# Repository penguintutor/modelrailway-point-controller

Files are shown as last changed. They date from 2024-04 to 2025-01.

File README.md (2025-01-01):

# Model railway point controller

The model railway point controller provides a way to control up to 4 points using a Raspberry Pi Pico W. It includes a MOSFET based capacitor discharge unit on the PCB and MOSFET controllers for each of the point motors.

It includes a second control board connected by I2C which can be connected to physical LEDs and switches to provide a way to control the points. The points can also be controlled using a web interface which can also be used in conjunction with GUI software to provide a touch screen interface.

# Installation

This version needs to be installed on a Raspberry Pi Pico W with the appropriate network enabled MicroPython. MicroPython can be installed through the Thonny editor.

To install the program, copy all the files in the pico-src directory to the top-level of the Raspberry Pi Pico. For the network connection you also need to create a file called secrets.py with details of your SSID and PASSWORD. The example below shows the formatting for the secrets.py file.

    SSID="NetworkSSID"
    PASSWORD="WiFiPassword"
    
## Configuration

The program can be run in two modes. 

* Access Point Mode (AP mode) - In this mode the Pico will act as a Wireless Access Point which you can connect to using another WiFi enabled device.
* Client Mode - In this mode you can connect to an existing wireless network

Note that in client mode it is currently blocking and will not operate until it has successfully connected to the network.

The mode is set by editing the entry "mode" in the pico-lights.py file. 

mode="ap"       # Use as an access point
mode="client"   # Use as a Wi-Fi client

## Running on startup

For the code to run automatically on start-up save the pico-point-controller.py file on your Pico as main.py.

## Using without the I2C control board

The board can be used in WiFi only mode, which does not use the I2C based switch and LED board. For that use the file pico-point-controller.wifionly.py instead of pico-point-controller.py (or save as main.py for auto-run) 

# More Information

For more details see [www.penguintutor.com/points](https://www.penguintutor.com/points)

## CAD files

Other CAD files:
enclosure/interface-only/point-controller-box-interface-v0.6.0.FCStd
enclosure/self-enclosed/point-controller-box-v0.5.5.FCStd

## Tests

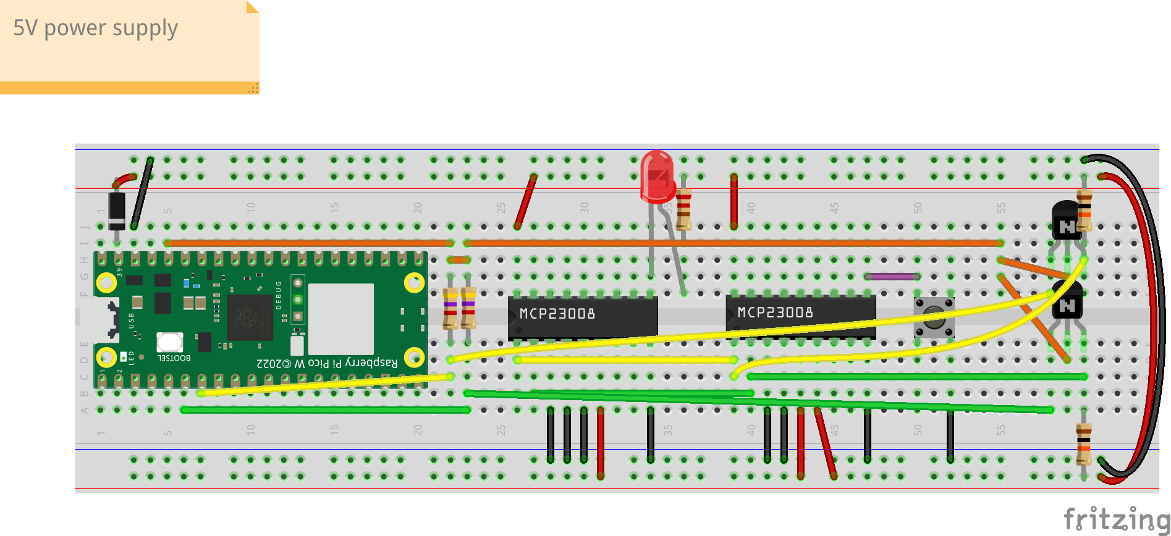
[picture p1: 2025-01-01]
electronics/breadboard-testing/switch-interfacev2_bb.png

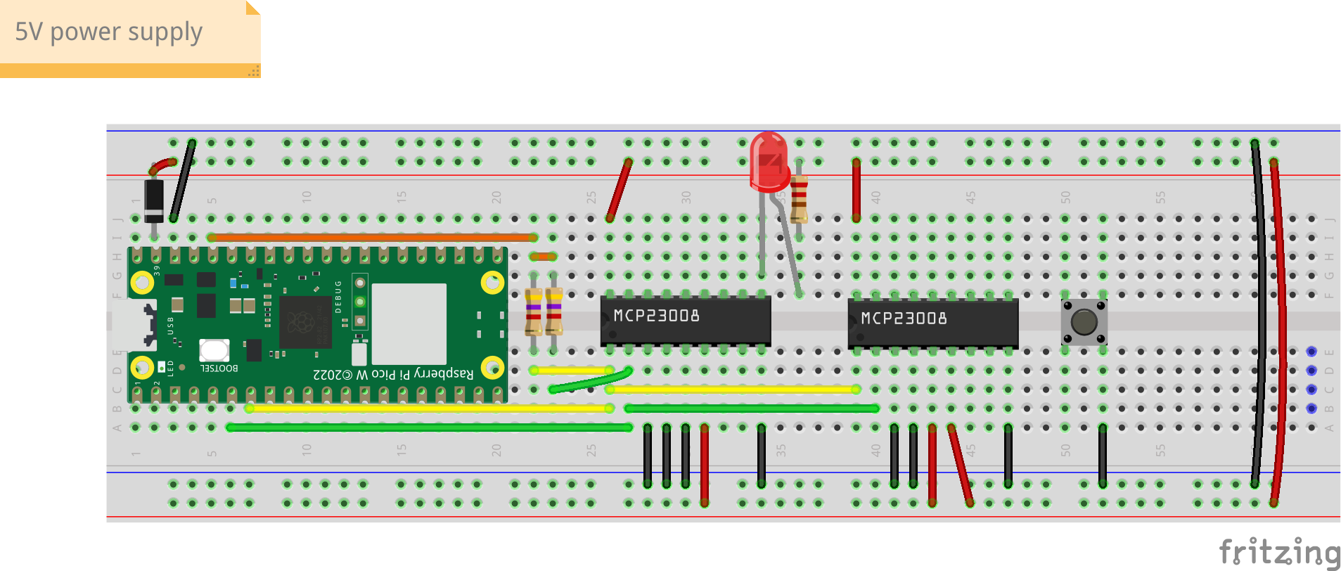
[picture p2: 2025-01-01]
electronics/breadboard-testing/switch-interface_bb.png

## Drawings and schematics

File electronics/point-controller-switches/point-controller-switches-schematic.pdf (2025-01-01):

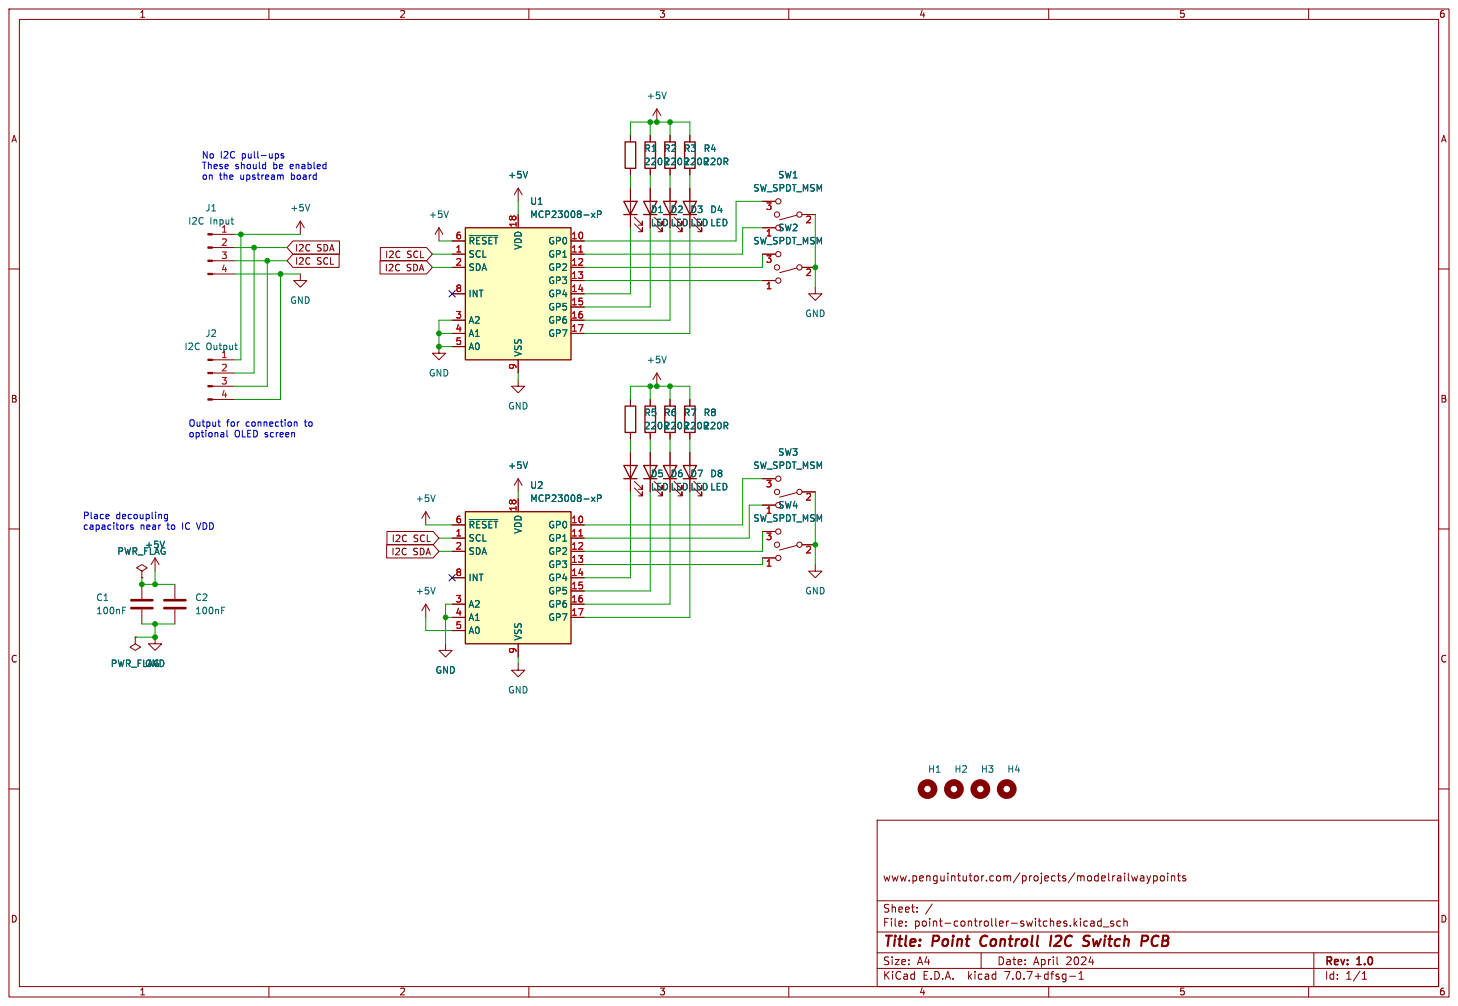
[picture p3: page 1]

I2C SDA I2C SCL No I2C pull-ups These should be enabled
I2C Output 1

File: point-controller-switches.kicad_sch Sheet: / www.penguintutor.com/projects/modelrailwaypoints GND

Id: 1/1 Title: Point Controll I2C Switch PCB

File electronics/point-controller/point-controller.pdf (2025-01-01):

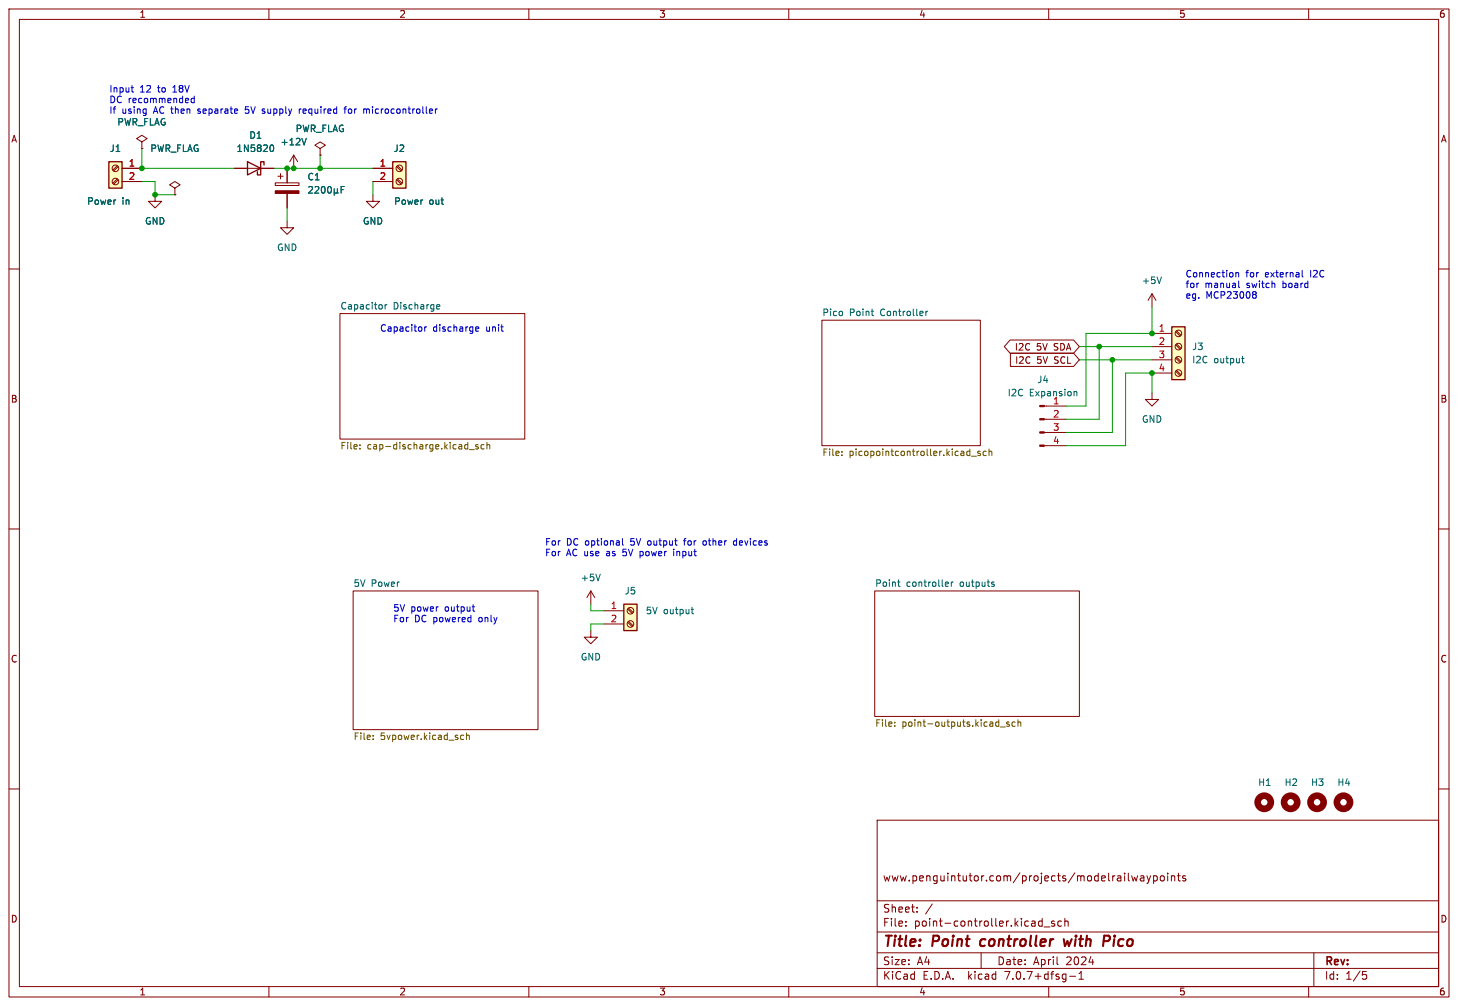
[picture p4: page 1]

Input 12 to 18V DC recommended

for manual switch board

File: point-controller.kicad_sch Sheet: / www.penguintutor.com/projects/modelrailwaypoints

Id: 1/5 Title: Point controller with Pico

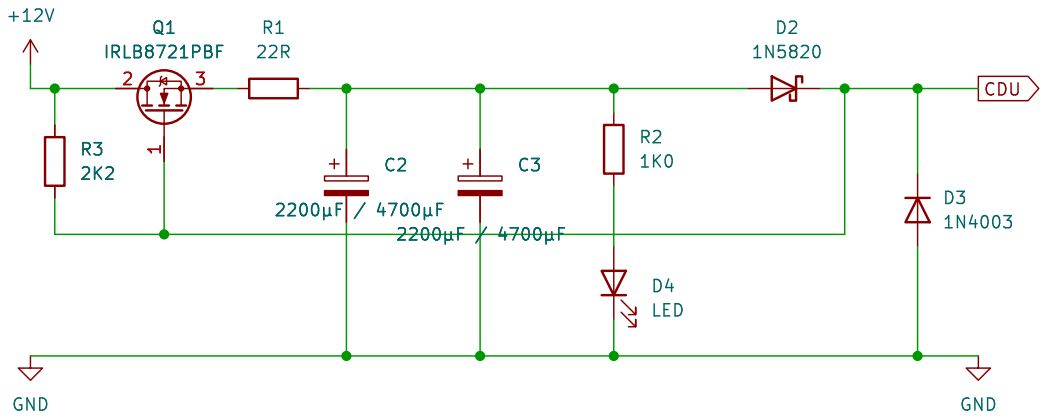
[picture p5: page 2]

www.penguintutor.com/projects/modelrailwaypoints

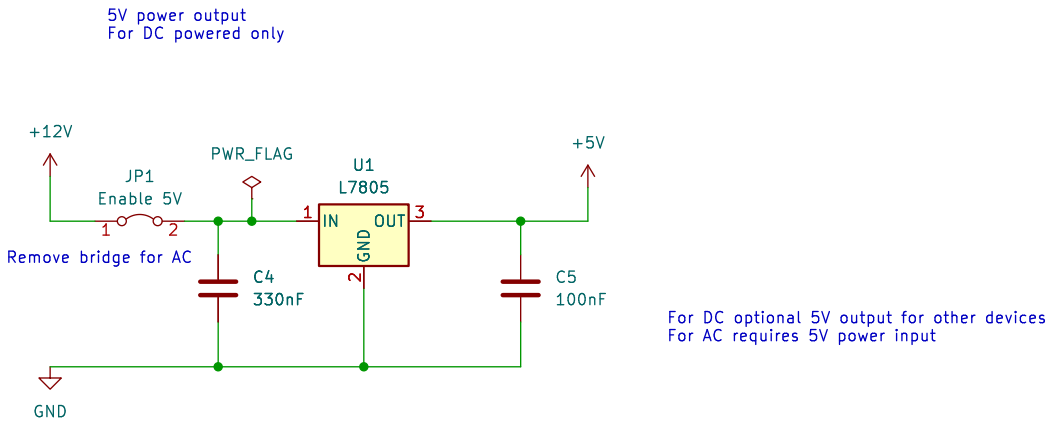
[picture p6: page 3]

330nF Remove bridge for AC

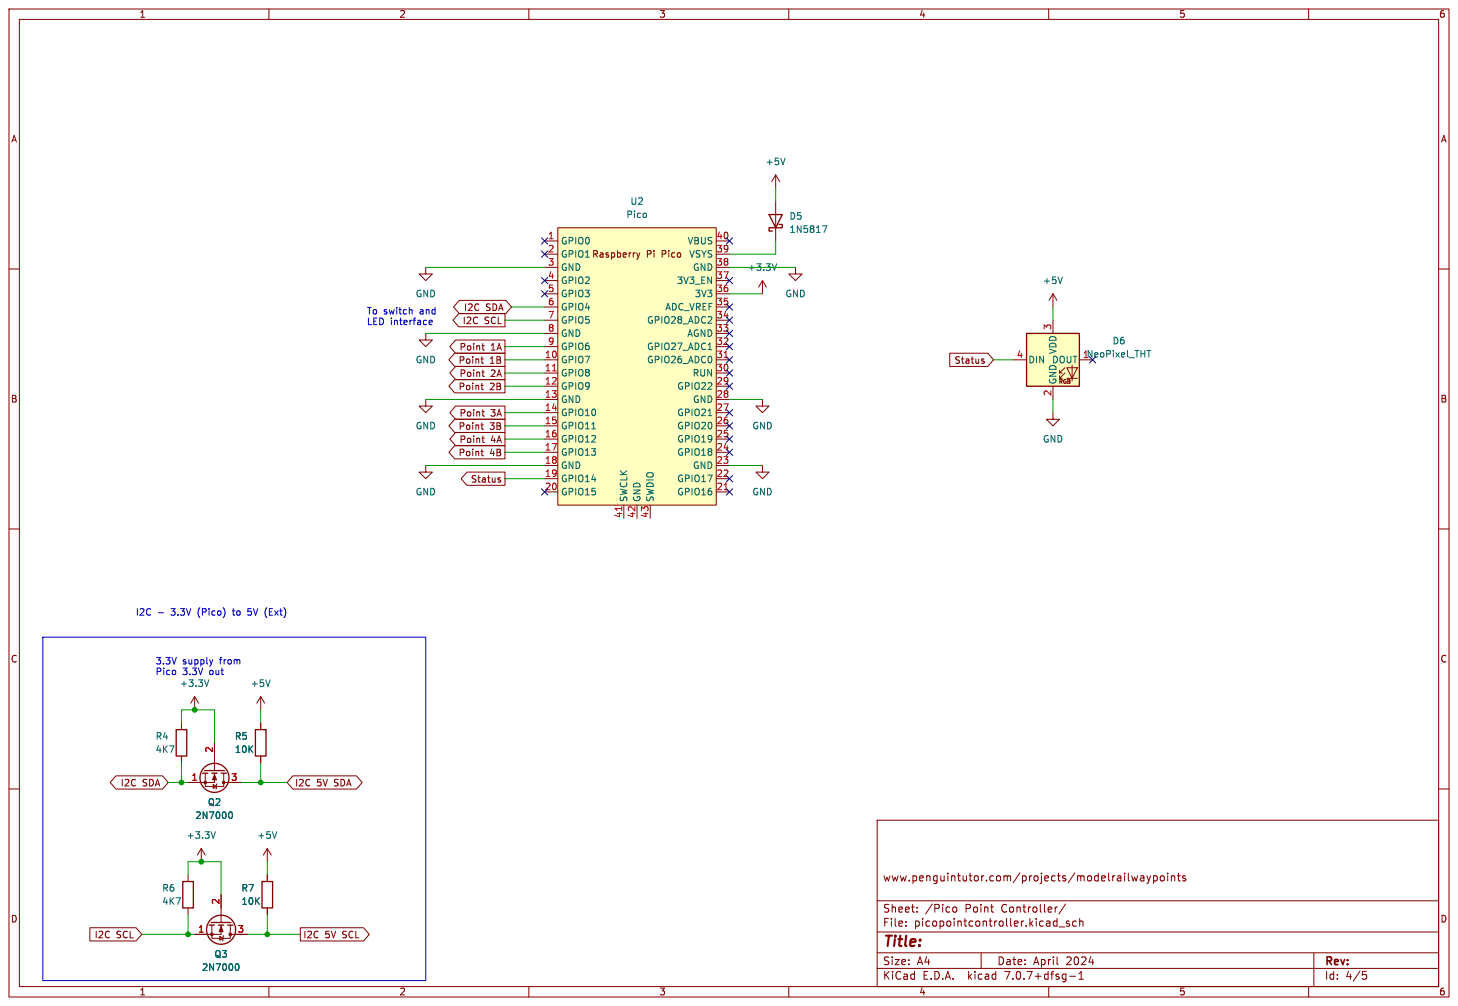
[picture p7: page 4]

I2C - 3.3V (Pico) to 5V (Ext) 3.3V supply from

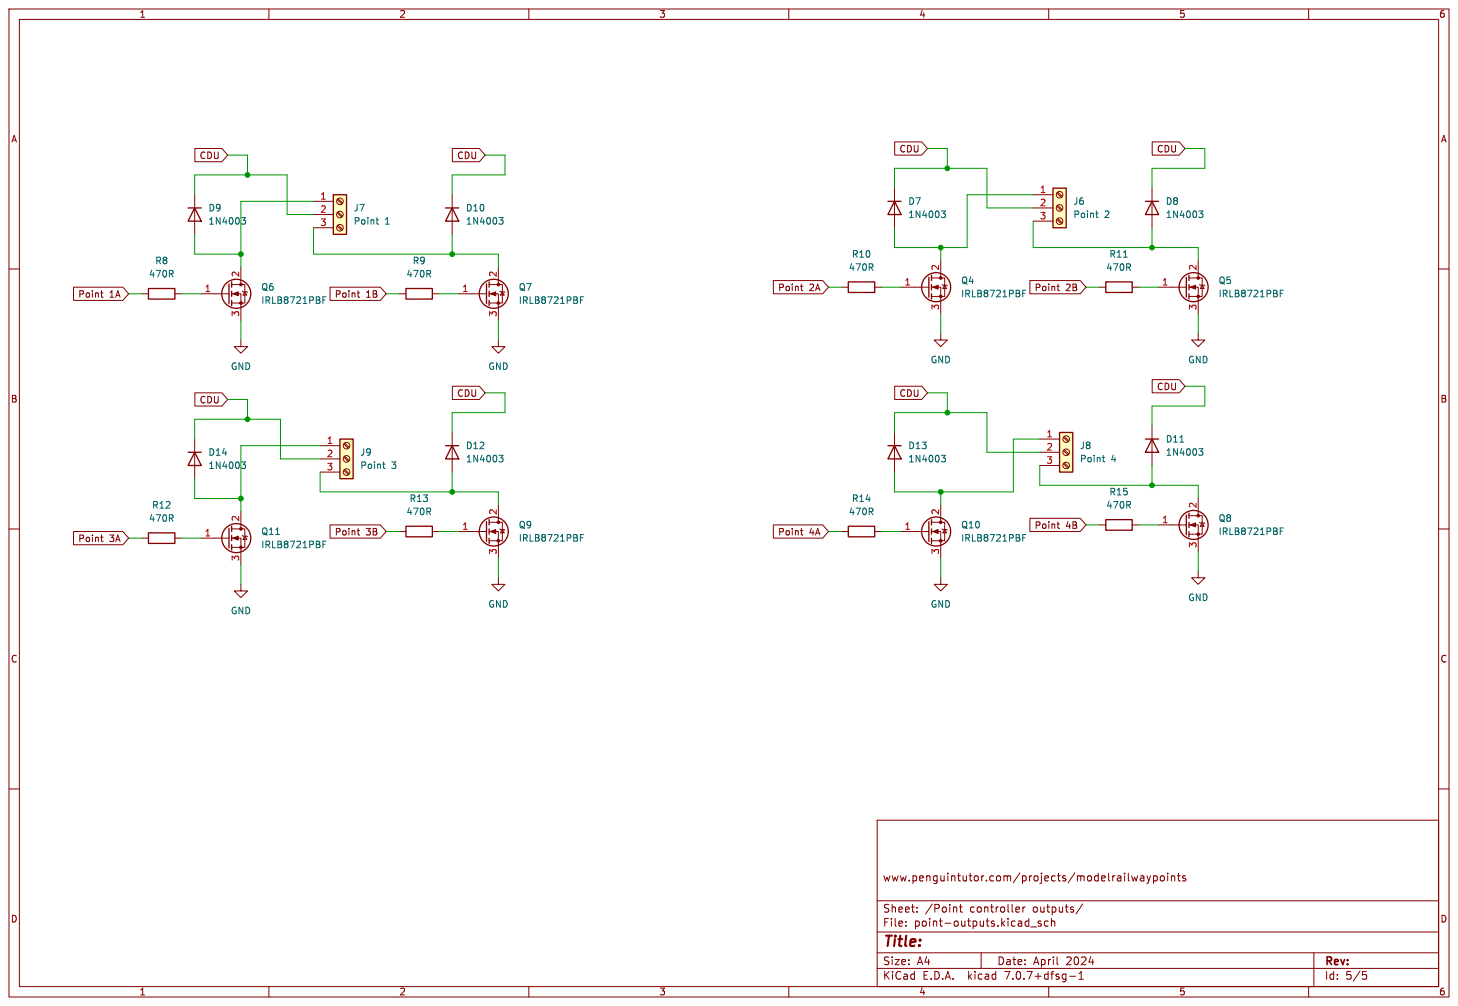
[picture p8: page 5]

www.penguintutor.com/projects/modelrailwaypoints

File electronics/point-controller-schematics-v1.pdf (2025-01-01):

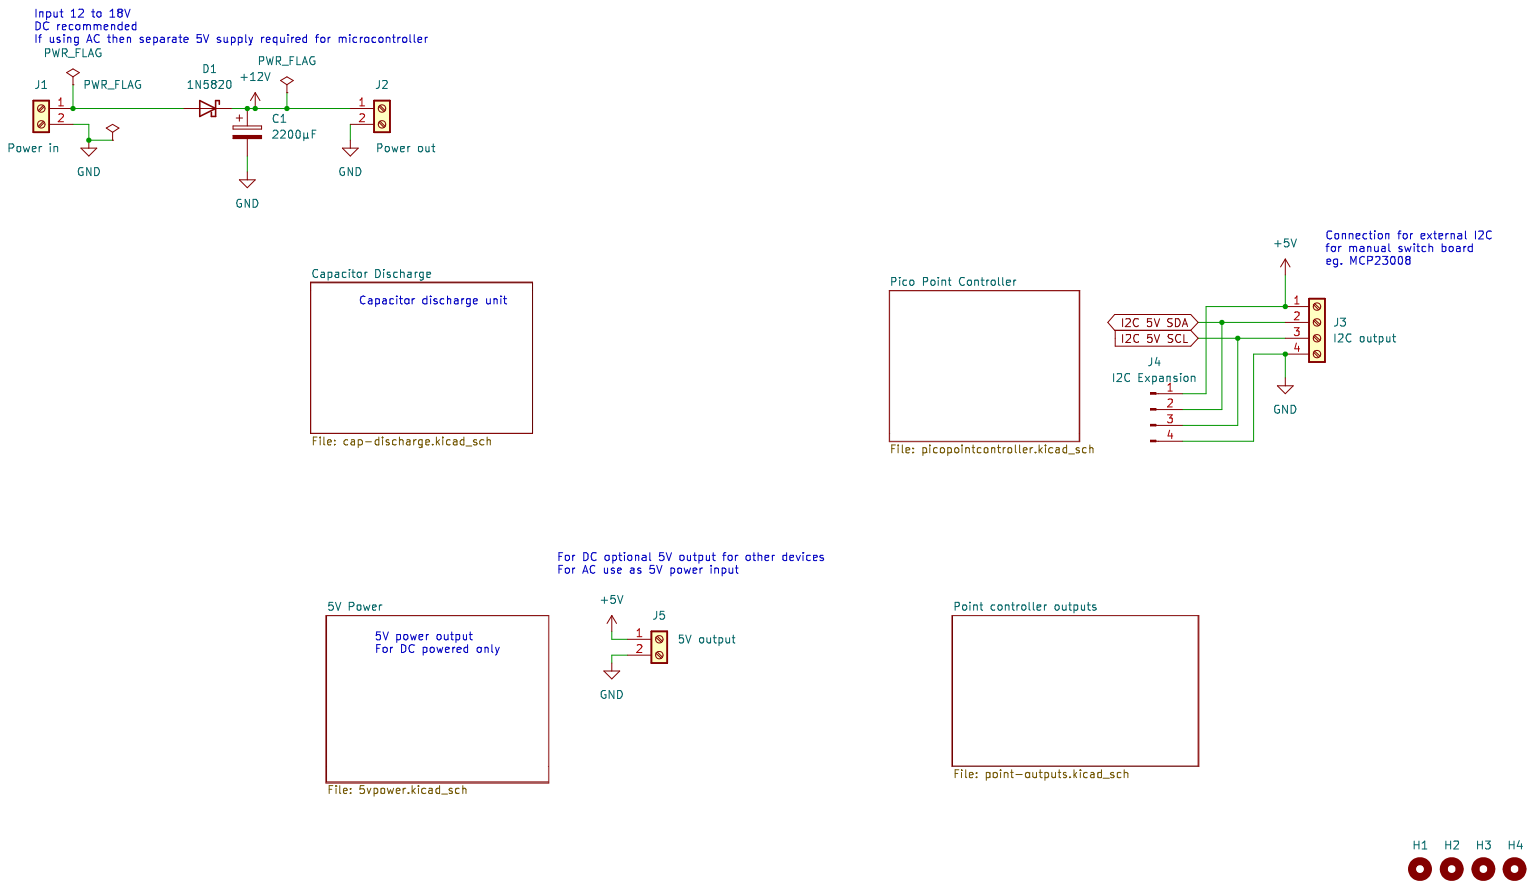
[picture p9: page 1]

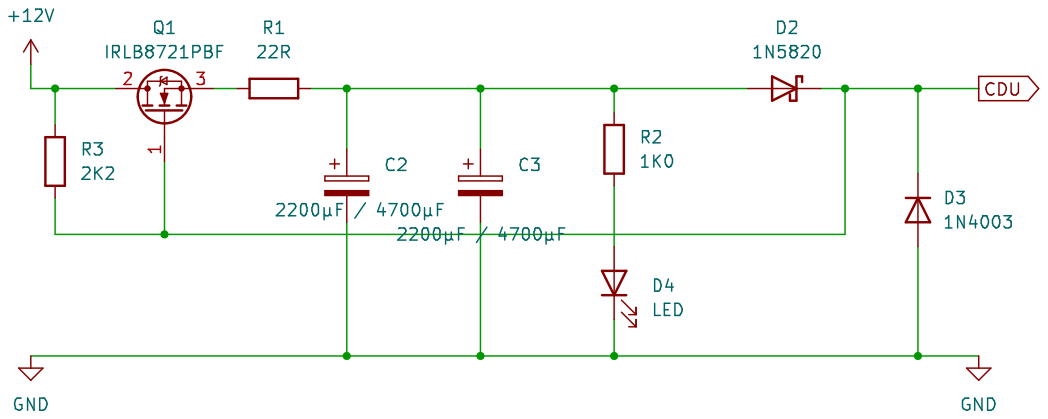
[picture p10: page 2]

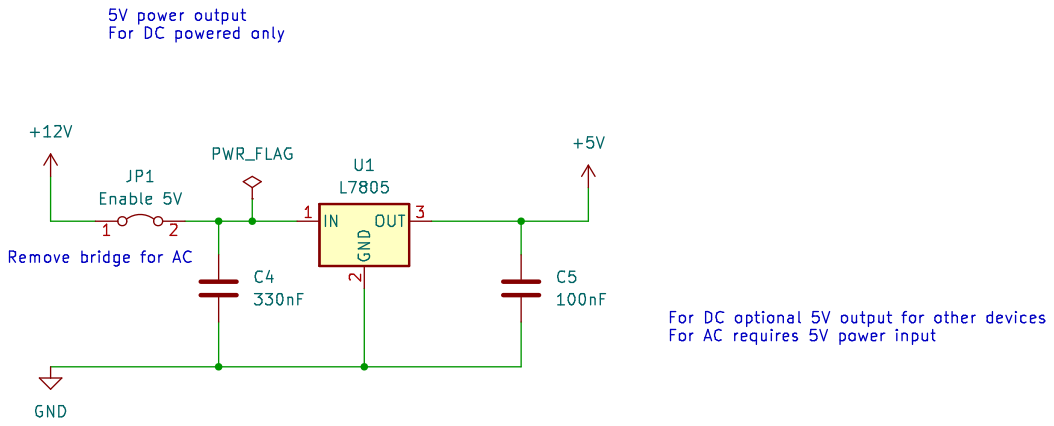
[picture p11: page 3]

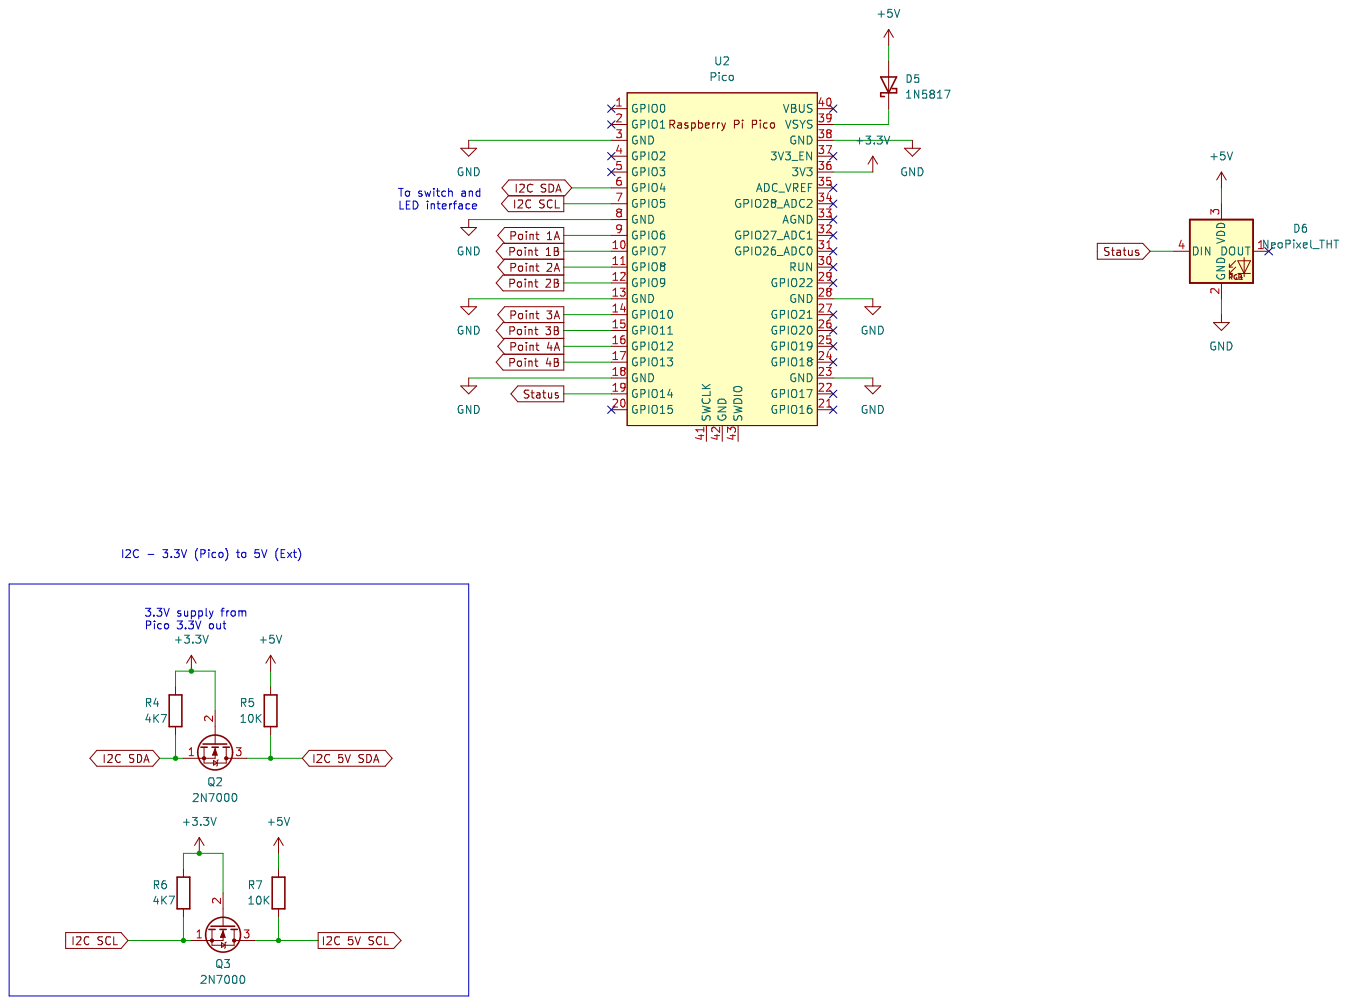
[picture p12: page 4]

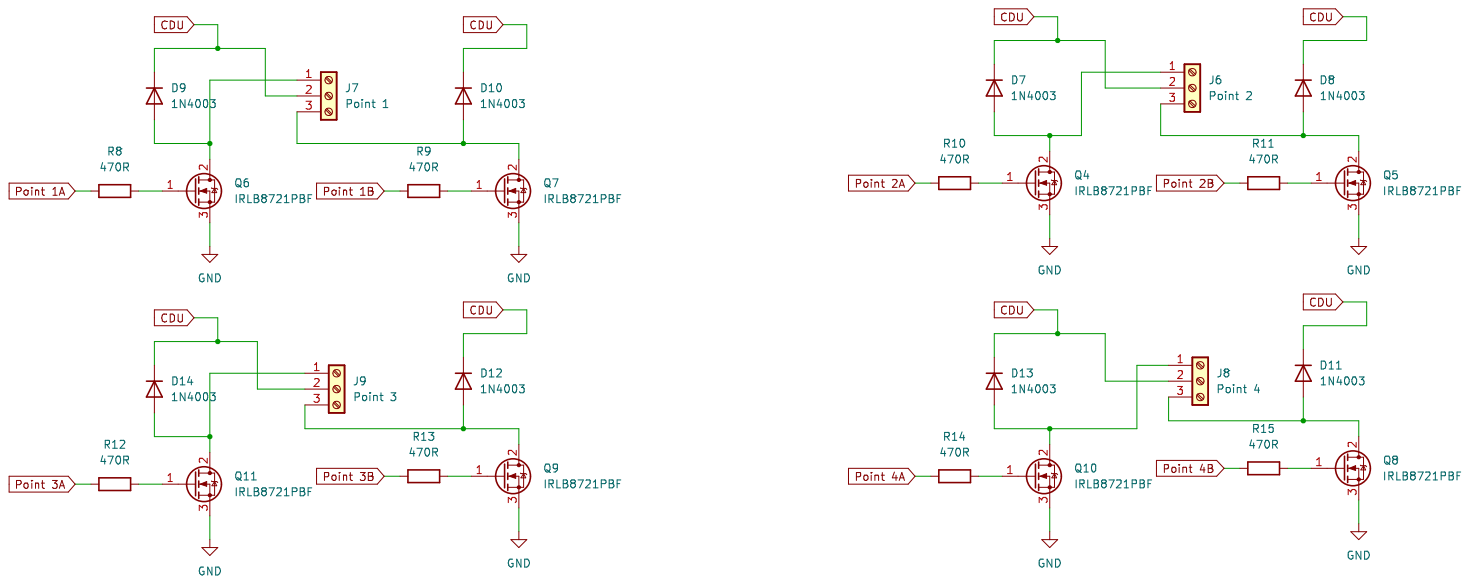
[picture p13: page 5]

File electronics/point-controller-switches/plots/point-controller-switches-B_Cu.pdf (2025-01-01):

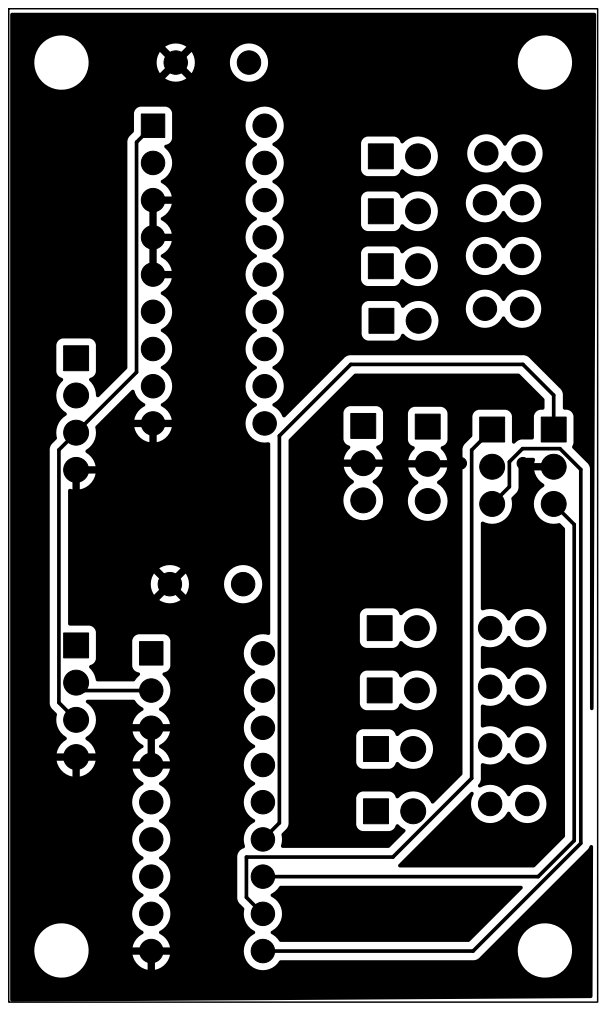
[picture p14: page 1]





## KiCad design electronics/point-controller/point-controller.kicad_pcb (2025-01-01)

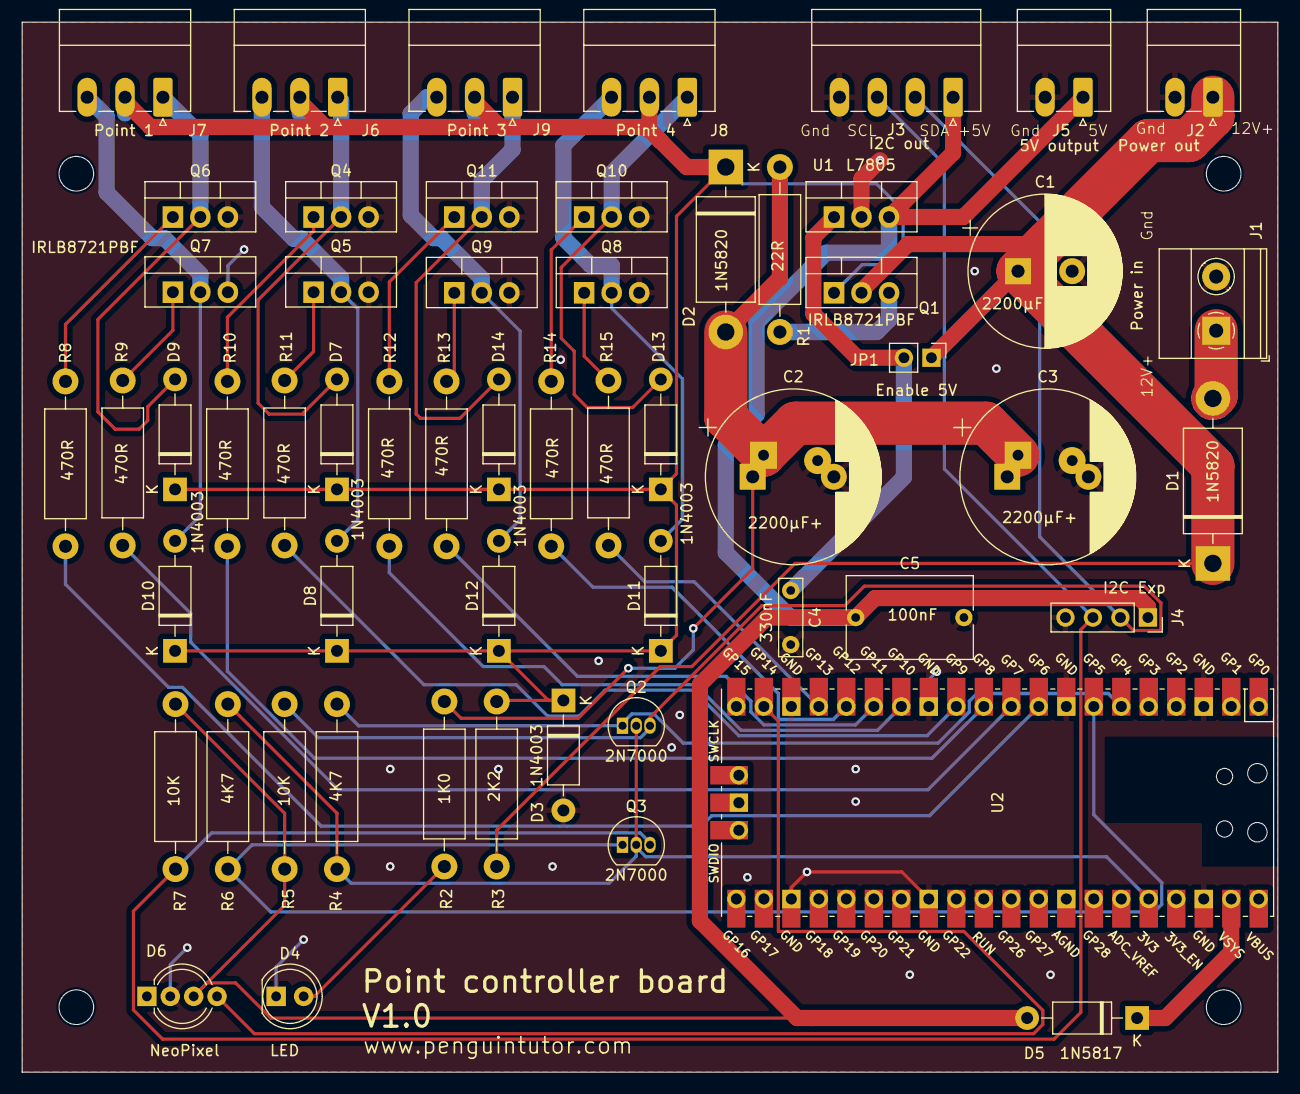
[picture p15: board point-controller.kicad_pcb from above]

Board: 2 copper layers, 116.0 x 97.0 mm, 61 parts (0 on the bottom side), 40 nets.

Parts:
C1: 2200μF; CP_Radial_D14.0mm_P5.00mm
C2, C3: 2200μF+; CP_Radial_D16.0mm_P7.50mm_P5.00mm
C4: 330nF; C_Rect_L7.0mm_W2.0mm_P5.00mm
C5: 100nF; C_Rect_L11.5mm_W7.5mm_P10.00mm_MKT
D1, D2: 1N5820; D_DO-201AD_P15.24mm_Horizontal
D3, D7, D8, D9, D10, D11, D12, D13, D14: 1N4003; D_DO-41_SOD81_P10.16mm_Horizontal
D4: LED; LED_D5.0mm
D5: 1N5817; D_DO-41_SOD81_P10.16mm_Horizontal
D6: NeoPixel; LED_D5.0mm-4_RGB_Wide_Pins
H1, H2, H3, H4: MountingHole; MountingHole_3.2mm_M3
J1: Power in; TerminalBlock_Phoenix_MKDS-1,5-2_1x02_P5.00mm_Horizontal
J2: Power out; PhoenixContact_MC_1,5_2-G-3.5_1x02_P3.50mm_Horizontal
J3: I2C out; PhoenixContact_MC_1,5_4-G-3.5_1x04_P3.50mm_Horizontal
J4: I2C Exp; PinSocket_1x04_P2.54mm_Vertical
J5: 5V output; PhoenixContact_MC_1,5_2-G-3.5_1x02_P3.50mm_Horizontal
J6: Point 2; PhoenixContact_MC_1,5_3-G-3.5_1x03_P3.50mm_Horizontal
J7: Point 1; PhoenixContact_MC_1,5_3-G-3.5_1x03_P3.50mm_Horizontal
J8: Point 4; PhoenixContact_MC_1,5_3-G-3.5_1x03_P3.50mm_Horizontal
J9: Point 3; PhoenixContact_MC_1,5_3-G-3.5_1x03_P3.50mm_Horizontal
JP1: Enable 5V; PinHeader_1x02_P2.54mm_Vertical
Q1, Q4, Q5, Q6, Q7, Q8, Q9, Q10, Q11: IRLB8721PBF; TO-220-3_Vertical
Q2, Q3: 2N7000; TO-92_Inline
R1: 22R; R_Axial_DIN0411_L9.9mm_D3.6mm_P15.24mm_Horizontal
R2: 1K0; R_Axial_DIN0411_L9.9mm_D3.6mm_P15.24mm_Horizontal
R3: 2K2; R_Axial_DIN0411_L9.9mm_D3.6mm_P15.24mm_Horizontal
R4, R6: 4K7; R_Axial_DIN0411_L9.9mm_D3.6mm_P15.24mm_Horizontal
R5, R7: 10K; R_Axial_DIN0411_L9.9mm_D3.6mm_P15.24mm_Horizontal
R8, R9, R10, R11, R12, R13, R14, R15: 470R; R_Axial_DIN0411_L9.9mm_D3.6mm_P15.24mm_Horizontal
U1: L7805; TO-220-3_Vertical
U2: Pico; RPi_Pico_SMD_TH

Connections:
+3.3V: Q2.2 (G), Q3.2 (G), R4.1, R6.1, U2.36 (3V3)
+5V: C5.1, D5.2 (A), D6.3 (VDD), J3.1, J4.1, J5.1, R5.1, R7.1, U1.3 (OUT)
+12V: C1.1, D1.1 (K), J2.1, JP1.1 (A), Q1.2 (D), R3.1
CDU: D2.1 (K), D3.1 (K), D7.1 (K), D8.1 (K), D9.1 (K), D10.1 (K), D11.1 (K), D12.1 (K), D13.1 (K), D14.1 (K), J6.2, J7.2, J8.2, J9.2, Q1.1 (G), R3.2
GND: C1.2, C2.2, C3.2, C4.2, C5.2, D3.2 (A), D4.1 (K), D6.2 (GND), J1.2, J2.2, J3.4, J4.4, J5.2, Q4.3 (S), Q5.3 (S), Q6.3 (S), Q7.3 (S), Q8.3 (S), Q9.3 (S), Q10.3 (S), Q11.3 (S), U1.2 (GND), U2.3 (GND), U2.8 (GND), U2.13 (GND), U2.18 (GND), U2.23 (GND), U2.28 (GND), U2.38 (GND)
I2C 5V SCL: J3.3, J4.3, Q3.3 (D), R7.2
I2C 5V SDA: J3.2, J4.2, Q2.3 (D), R5.2
I2C SCL: Q3.1 (S), R6.2, U2.7 (GPIO5)
I2C SDA: Q2.1 (S), R4.2, U2.6 (GPIO4)
unnamed: D1.2 (A), J1.1
unnamed: C2.1, C3.1, D2.2 (A), R1.2, R2.1
unnamed: D4.2 (A), R2.2
unnamed: D5.1 (K), U2.39 (VSYS)
unnamed: D7.2 (A), J6.1, Q4.2 (D)
unnamed: D8.2 (A), J6.3, Q5.2 (D)
unnamed: D9.2 (A), J7.1, Q6.2 (D)
unnamed: D10.2 (A), J7.3, Q7.2 (D)
unnamed: D11.2 (A), J8.3, Q8.2 (D)
unnamed: D12.2 (A), J9.3, Q9.2 (D)
unnamed: D13.2 (A), J8.1, Q10.2 (D)
unnamed: D14.2 (A), J9.1, Q11.2 (D)
unnamed: C4.1, JP1.2 (B), U1.1 (IN)
unnamed: Q1.3 (S), R1.1
unnamed: Q4.1 (G), R10.2
unnamed: Q5.1 (G), R11.2
unnamed: Q6.1 (G), R8.2
unnamed: Q7.1 (G), R9.2
unnamed: Q8.1 (G), R15.2
unnamed: Q9.1 (G), R13.2
unnamed: Q10.1 (G), R14.2
unnamed: Q11.1 (G), R12.2
Point 1A: R8.1, U2.9 (GPIO6)
Point 1B: R9.1, U2.10 (GPIO7)
Point 2A: R10.1, U2.11 (GPIO8)
Point 2B: R11.1, U2.12 (GPIO9)
Point 3A: R12.1, U2.14 (GPIO10)
Point 3B: R13.1, U2.15 (GPIO11)
Point 4A: R14.1, U2.16 (GPIO12)
Point 4B: R15.1, U2.17 (GPIO13)
Status: D6.4 (DIN), U2.19 (GPIO14)

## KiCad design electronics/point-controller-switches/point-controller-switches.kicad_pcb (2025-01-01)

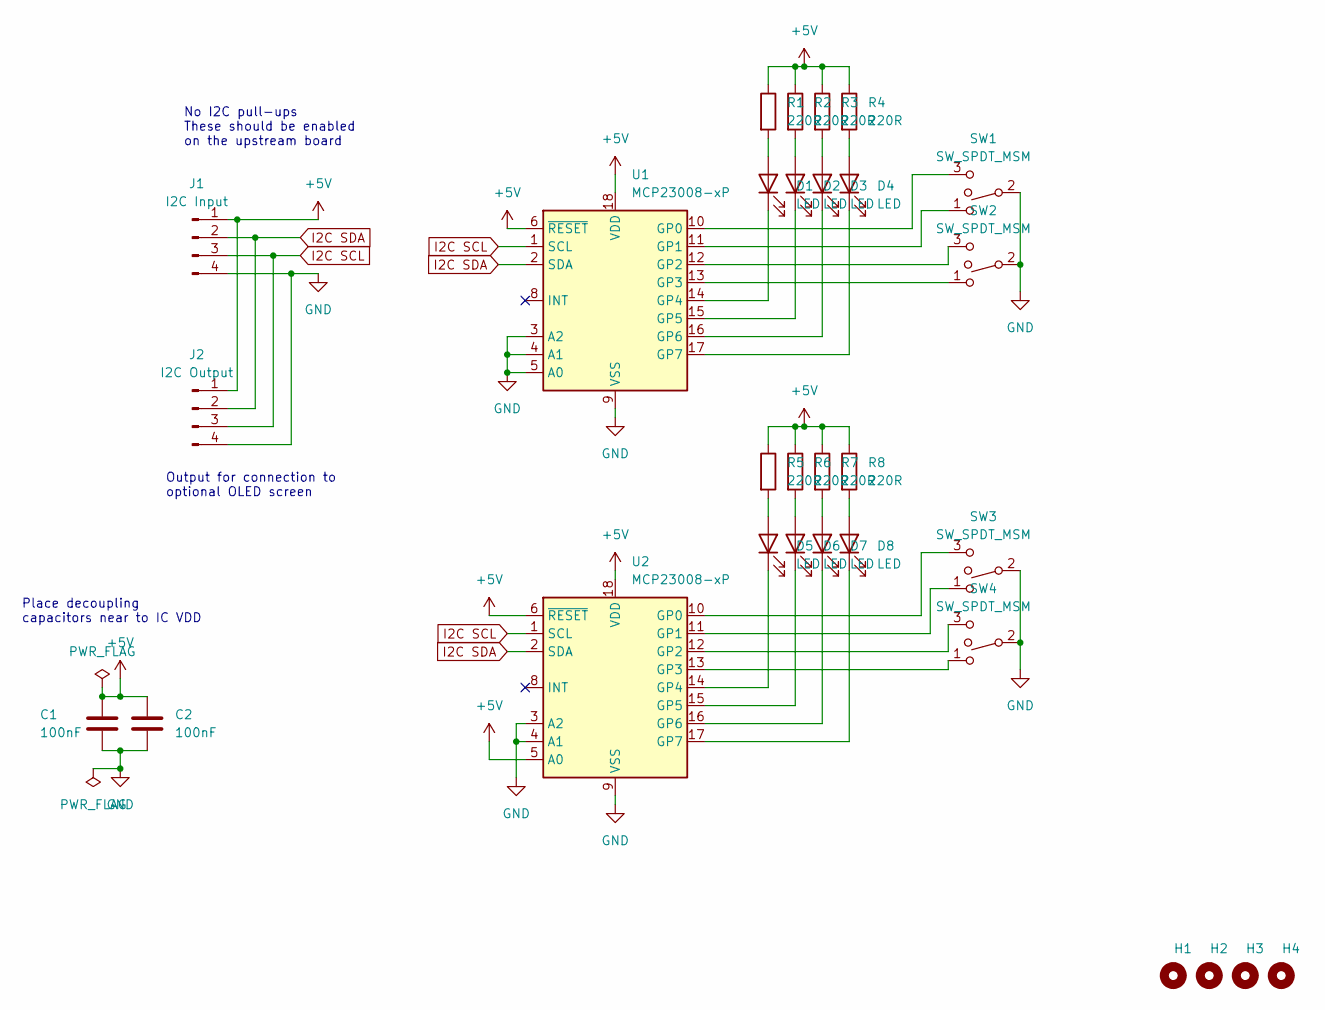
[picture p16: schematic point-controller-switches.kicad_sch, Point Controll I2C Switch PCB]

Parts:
C1, C2: 100nF; C_Disc_D4.3mm_W1.9mm_P5.00mm
D1, D2, D3, D4, D5, D6, D7, D8: LED; PinHeader_1x02_P2.54mm_Vertical
H1, H2, H3, H4: MountingHole; MountingHole_3.2mm_M3
J1: I2C Input; PinHeader_1x04_P2.54mm_Vertical
J2: I2C Output; PinHeader_1x04_P2.54mm_Vertical
R1, R2, R3, R4, R5, R6, R7, R8: 220R; R_Axial_DIN0207_L6.3mm_D2.5mm_P2.54mm_Vertical
SW1, SW2, SW3, SW4: SW_SPDT_MSM; PinHeader_1x03_P2.54mm_Vertical
U1, U2: MCP23008-xP; DIP-18_W7.62mm

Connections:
+5V: C1.1, C2.1, J1.1, J2.1, R1.1, R2.1, R3.1, R4.1, R5.1, R6.1, R7.1, R8.1, U1.6 (~RESET), U1.18 (VDD), U2.5 (A0), U2.6 (~RESET), U2.18 (VDD)
GND: C1.2, C2.2, J1.4, J2.4, SW1.2, SW2.2, SW3.2, SW4.2, U1.3 (A2), U1.4 (A1), U1.5 (A0), U1.9 (VSS), U2.3 (A2), U2.4 (A1), U2.9 (VSS)
I2C SCL: J1.3, J2.3, U1.1 (SCL), U2.1 (SCL)
I2C SDA: J1.2, J2.2, U1.2 (SDA), U2.2 (SDA)
unnamed: D1.2 (A), R1.2
unnamed: D1.1 (K), U1.14 (GP4)
unnamed: D2.2 (A), R2.2
unnamed: D2.1 (K), U1.15 (GP5)
unnamed: D3.2 (A), R3.2
unnamed: D3.1 (K), U1.16 (GP6)
unnamed: D4.2 (A), R4.2
unnamed: D4.1 (K), U1.17 (GP7)
unnamed: D5.2 (A), R5.2
unnamed: D5.1 (K), U2.14 (GP4)
unnamed: D6.2 (A), R6.2
unnamed: D6.1 (K), U2.15 (GP5)
unnamed: D7.2 (A), R7.2
unnamed: D7.1 (K), U2.16 (GP6)
unnamed: D8.2 (A), R8.2
unnamed: D8.1 (K), U2.17 (GP7)
unnamed: SW1.3, U1.10 (GP0)
unnamed: SW1.1, U1.11 (GP1)
unnamed: SW2.3, U1.12 (GP2)
unnamed: SW2.1, U1.13 (GP3)
unnamed: SW3.3, U2.10 (GP0)
unnamed: SW3.1, U2.11 (GP1)
unnamed: SW4.3, U2.12 (GP2)
unnamed: SW4.1, U2.13 (GP3)

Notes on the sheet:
Place decoupling capacitors near to IC VDD
Output for connection to optional OLED screen
No I2C pull-ups These should be enabled on the upstream board

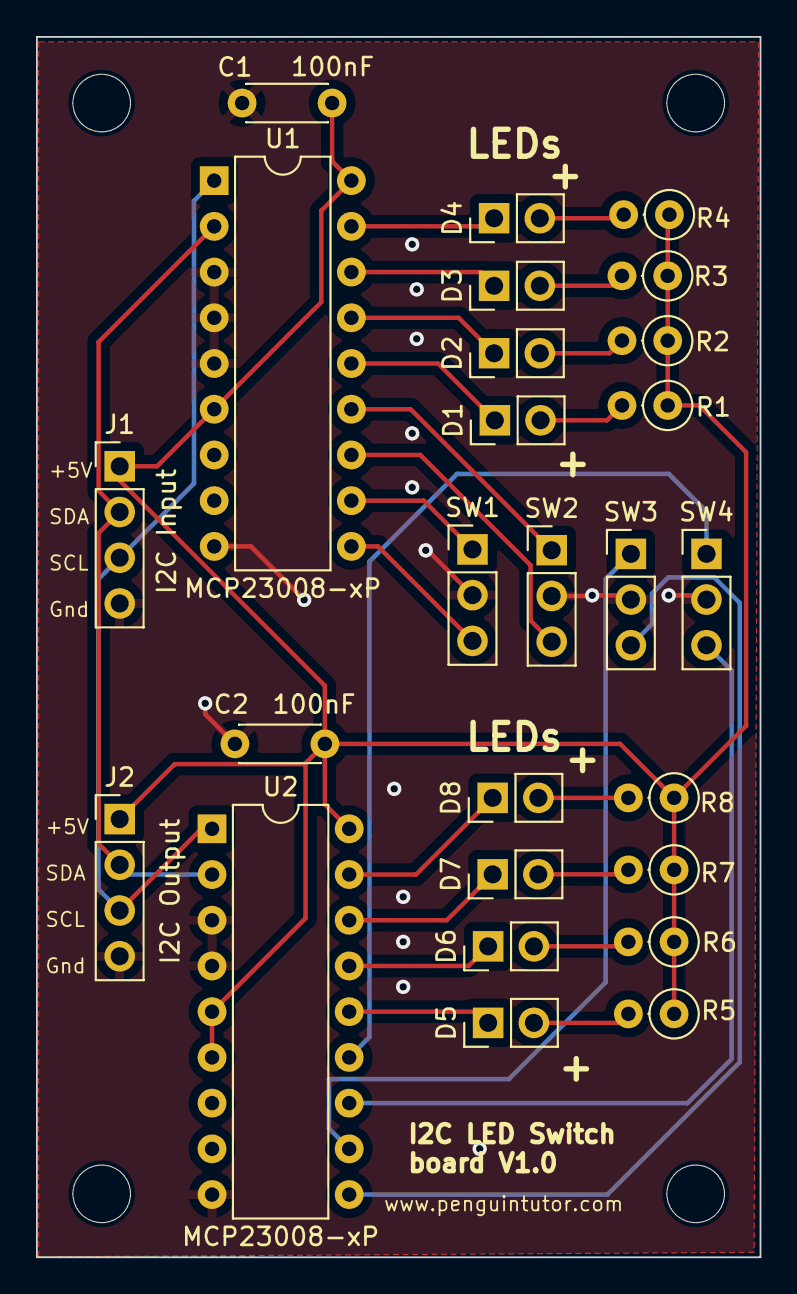
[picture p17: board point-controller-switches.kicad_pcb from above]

Board: 2 copper layers, 40.2 x 67.8 mm, 30 parts (0 on the bottom side), 28 nets.

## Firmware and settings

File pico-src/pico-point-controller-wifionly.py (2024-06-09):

# Code for controlling Model Railway points
# Point controller board
# Also needs secrets.py with WiFi login details
# For more details see: https://www.penguintutor.com/points

# Alternative to pico-point-controller.py to allow testing of
# main board without being connected to add-on switch board

from machine import Pin
from utime import sleep
import network
import socket
import uasyncio as asyncio
import secrets
import re
from url_handler import URL_Handler
from pixelstatus import *
from point import Point
from controller import Controller

# Mode can be ap (access point where the Pico acts as a web server)
# or "client" [default] which connects to an existing network
# Note that client mode is blocking and will not run the rest of the code
# until a network connection is established
mode="client"

# Do we display light sequence on startup - helpful to test if working
intro = True

# All documents in DocumentRoot are publically accessible
DocumentRoot = "public/"

# If ip_config not blank then use for network config
# otherwise set to "" to use dhcp
ip_config = ("192.168.0.53", "255.255.255.0", "192.168.0.1", "8.8.8.8")

# Indexed at 0 (board labelling is 1)

controller = Controller((0,5,4), (0, 32, 33), i2c_control=False)

# Each of the points is created as an instance of point object
# Each of the pins is given a tuple representing controller number, followed by port number
# Pico is controller 0, MCP23008 are 1 and 2
# Point class uses controller, point0, point1, switch0, switch1, led0, led1
points = [
    Point(controller, (0,6), (0, 7), (1,0), (1,1), (1,4), (1,5)),
    Point(controller, (0,8), (0, 9), (1,2), (1,3), (1,6), (1,7)),
    Point(controller, (0,10), (0, 11), (2,0), (2,1), (2,4), (2,5)),
    Point(controller, (0,12), (0, 13), (2,2), (2,3), (2,6), (2,7))
]



url = URL_Handler(DocumentRoot)

      
def connect():
    #Connect to WLAN
    if mode== "ap":
        # Access Point mode
        ip = connect_ap_mode()
    else:
        ip = connect_client_mode()
    return ip
    


def connect_ap_mode ():
    wlan = network.WLAN(network.AP_IF)
    wlan.config(essid=secrets.SSID, password=secrets.PASSWORD)
    wlan.active(True)
    while wlan.active() == False:
        print ('Trying to setup AP mode')
    ip = wlan.ifconfig()[0]
    print('AP Mode is active')
    print('Connect to Wireless Network '+secrets.SSID)
    print('Connect to IP address '+ip)
    return ip

def connect_client_mode ():
    wlan = network.WLAN(network.STA_IF)
    wlan.active(True)
    wlan.config(pm = 0xa11140) # Disable power saving mode
    if ip_config != "":
        wlan.ifconfig(ip_config)
    wlan.connect(secrets.SSID, secrets.PASSWORD)
    while wlan.isconnected() == False:
        print('Waiting for connection...')
        sleep(1)
    ip = wlan.ifconfig()[0]
    print('Connect to IP address '+ip)    
    return ip



def setup_pins ():
    # List of inputs and outputs used in setup
    inputs = []
    outputs = []

    # Setup inputs and outputs
    for this_point in points:
        inputs.extend(this_point.get_inputs())
        outputs.extend(this_point.get_outputs())
    # Wifi only no inputs - next line commented out
    controller.set_inputs(inputs)
    controller.set_outputs(outputs)
    
    # Set all points to unknown state (both LEDs off)
    for this_point in points:
        this_point.unknown()
        
    if intro == True:
        # Quick flash intro
        for this_point in points:
            this_point.set_led(0, 1)
            sleep(0.5)
            this_point.set_led(0, 0)
            this_point.set_led(1, 1)
            sleep(0.5)
            this_point.set_led(1, 0)
            

async def serve_client(reader, writer):
    status_active()
    print("Client connected")
    request_line = await reader.readline()
    print("Request:", request_line)
    # We are not interested in HTTP request headers, skip them
    while await reader.readline() != b"\r\n":
        pass
    
    request = request_line.decode("utf-8")
    
    # point change request (returns own string)
    point_change = url.change_point(request)
    if point_change != None:
        if (point_change[1] == 1):
            points[point_change[0]].set_point(1)
        elif (point_change[1] == 2):
            points[point_change[0]].set_point(2)
        # Ignore any other values (code doesn't support any)
        # Return status - currently just text (will change to JSON)
        writer.write('HTTP/1.0 200 OK\r\nContent-type: text/text\r\n\r\n')
        writer.write('Status ...')
    
    
    else:
        # Otherwise is this is static file request
        
        url_value, url_file, url_type = url.validate_file(request)

        writer.write('HTTP/1.0 {} OK\r\nContent-type: {}\r\n\r\n'.format(url_value, url_type))
        # Send file 1kB at a time (avoid problem with large files exceeding available memory)
        with open(DocumentRoot+url_file, "rb") as read_file:
            data = read_file.read(1024)
            while data:
                writer.write(data)
                await writer.drain()
                data = read_file.read(1024)
            read_file.close()

    await writer.wait_closed()
    print("Client disconnected")

    status_ready()

# Initialise Wifi
async def main ():
    # Set Status LED to Red (power on)
    status_power()
    setup_pins ()
    print ("Connecting to network")
    try:
        ip = connect()
    except KeyboardInterrupt:
        machine.reset
    print ("IP address", ip)
    asyncio.create_task(asyncio.start_server(serve_client, "0.0.0.0", 80))
    print ("Web server listening on", ip)
    status_ready()
    while True:
        #onboard.on()
        # Enable following line for heartbeat debug messages
        #print ("heartbeat")
        await asyncio.sleep(0.25)
        # Check gpio pins 10 times between checks for webpage (5 secs)
        for i in range (0, len(points)):
            #print (f"Switch {i} is {points[i].switch_position()}")
            pos = points[i].switch_position()
            if (pos == 0):
                # ignore
                pass
            else:
                points[i].set_point(pos)
                
#        for i in range (0, 5):
#            check_gpio_buttons()
    



if __name__ == '__main__':
    try:
        asyncio.run(main())
    finally:
        asyncio.new_event_loop()

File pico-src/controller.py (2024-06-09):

# This assumes that there are two MCP23008 connected to pins 4 & 5 of Pico
# First has all addresses to 0 = address 32, second has a0 to 1 = address 33
# Also needs mcp23008.py from:
# https://github.com/CrankshawNZ/Micropython/blob/master/mcp23008.py

from machine import Pin, I2C
from mcp23008 import MCP23008
from controllerpico import ControllerPico

class Controller:
    
    # Uses addresses - for Pico use address 0, controllers use address
    # I2C address should be (id, scl, sda) eg. (0,5,4)
    # I2C control - is whether we have an i2c board connected - if not then WiFi only
    # Allows for testing of main board without needing external board
    def __init__(self, i2c_address, controller_addresses, i2c_control=True):
        self.controller_address = controller_addresses
        self.controller = []
        self.i2c_control = i2c_control

        i2c = I2C(id=i2c_address[0], scl=Pin(i2c_address[1]), sda=Pin(i2c_address[2]), freq=100000)
        
        print ("I2C Scan")
        print (i2c.scan())
        
        #print ("Hex version")
        #addrs = [hex(addr) for addr in i2c.scan()]
        #print(addrs)

        for this_controller in self.controller_address:
            if this_controller == 0:
                # Create a Pico device
                self.controller.append(ControllerPico())
            else:
                self.controller.append(MCP23008(i2c, this_controller))

    def set_inputs (self, inputs):
        for this_input in inputs:
            # If no external board then skip any that are not on local
            if self.i2c_control == False and this_input[0] != 0:
                continue
            self.controller[this_input[0]].setPinDir(this_input[1], 1)
            # Also set pullup
            self.controller[this_input[0]].setPullupOn(this_input[1])
                
    def set_outputs (self, outputs):
        for this_output in outputs:
            # If no external board then skip any that are not on local
            if self.i2c_control == False and this_output[0] != 0:
                continue
            self.controller[this_output[0]].setPinDir(this_output[1], 0)
            # Set to low
            self.controller[this_output[0]].setPinLow(this_output[1])
            
    # State = 1 for high and 0 for low (note that LEDs are opposite - see point.py)
    def set_pin (self, addr, state):
        # If no external board then skip any that are not on local
        if self.i2c_control == False and addr[0] != 0:
            return
        if state == 1:
            self.controller[addr[0]].setPinHigh(addr[1])
        else:
            self.controller[addr[0]].setPinLow(addr[1])

    def get_pin (self, addr):
        # If no external board then skip any that are not on local
        if self.i2c_control == False and addr[0] != 0:
            return 1
        return self.controller[addr[0]].readPin(addr[1])
    
    # Depreciated - use get_pin instead
    def get_input (self, addr):
        # If no external board then skip any that are not on local
        if self.i2c_control == False and addr[0] != 0:
            return 1
        return self.controller[addr[0]].readPin(addr[1])
        
    


# Read inputs
#for i in range (0, 4):
#    print (f"Pin A{i} is {exp1.readPin(i)}")

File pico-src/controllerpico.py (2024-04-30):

# Class allowing control of Pico pins with same interface
# as MCP23008

from machine import Pin, I2C

class ControllerPico:
    def __init__(self):
        # Use to hold pins - uses dictionary as not all pins used
        self.pins = {}
    
    # methods to emulate MCP23008 on the Pico
    def setPinDir(self, i, direction):
        # If existing
        #if i in pins:
        # If input (direction = 1)
        if direction == 1:
            self.pins[i] = Pin(i, Pin.IN)
        else:
            self.pins[i] = Pin(i, Pin.OUT)
            
    # Setup pull-up - most be defined as an input first
    def setPullupOn(self, i):
        self.pins[i].pull(Pin.PULL_UP)
        
    def setPinLow(self, i):
        self.pins[i].low()
        
    def setPinHigh(self, i):
        self.pins[i].high()

# Set first 4 to inputs with pull-ups 

# for i in range (0, 4):
# 
#     exp1.setPinDir(i, 1)
#     exp1.setPullupOn(i)
# 
# 
# # Set next 4 pins to outputs - set low (turn LEDs on)
# 
# for i in range (4, 8):
# 
#     exp1.setPinDir(i, 0)
# 
#     exp1.setPinLow(i)
# 
#     exp2.setPinDir(i, 0)
# 
#     exp2.setPinLow(i)
# 
#     
# 
# # Read inputs
# 
# for i in range (0, 4):
# 
#     print (f"Pin A{i} is {exp1.readPin(i)}")
# 
#     print (f"Pin B{i} is {exp2.readPin(i)}")
# 

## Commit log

2024-04-30 Initial version for Pico W
2024-06-09 Add alternative wifionly version to allow testing of main board without i2c board
2024-06-09 bug fix for point numbering
    [controller.py]
2025-01-01 Add electronics circuit design files
    [5vpower.kicad_sch, cap-discharge.kicad_sch, picopointcontroller.kicad_sch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]
2025-01-01 Add initial enclosure design
    [point-controller-box-v0.5.5.FCStd]
2025-01-01 Add initial design for interface only PCB
    [point-controller-box-interface-v0.6.0.FCStd]
2025-01-02 Add enclosure files with engraving / etch details
